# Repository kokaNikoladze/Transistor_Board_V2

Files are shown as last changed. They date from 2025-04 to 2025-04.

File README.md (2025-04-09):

MIDI-CONTROLLED TRANSISTOR DRIVER
---------------------------------

This Arduino sketch turns MIDI messages into PWM voltage outputs to control transistors,
analog circuits, or other devices via 8 digital pins (pins 4–11).

FEATURES:
- Responds to USB MIDI Note On/Off: 
  - Note velocity controls output voltage (0–16383).
- Control Change (CC) support:
  - Channel 2: 7-bit control (0–127), scaled to 14-bit PWM.
  - Channel 1: High-resolution 14-bit NRPN-style control with exponential response.
    (MSB on CC < 64, LSB on CC >= 64)

PIN ASSIGNMENTS:
- Outputs 1–8 → Digital pins 4–11

NRPN FORMAT (FOR CHANNEL 1 HIGH-RES CONTROL):
- Input value: 0–16383
- MSB = value / 128     → Send to control #1 (or any CC < 64)
- LSB = value % 128     → Send to control #65 (or any CC >= 64)
- IMPORTANT: Send LSB first, then MSB

OTHER NOTES:
- Uses 14-bit PWM resolution
- PWM frequency set on pin 1 to 18.384kHz
- Includes exponential curve: pow(result / 16383.0, 3)
- Built for Teensy or other boards with analogWriteResolution()

DEPENDENCIES:
- usbMIDI library (Teensy compatible)

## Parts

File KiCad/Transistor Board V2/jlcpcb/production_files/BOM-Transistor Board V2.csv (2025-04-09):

Comment | Designator | Footprint | LCSC | Quantity
R_Small | R10,R11,R12,R5,R6,R7,R8,R9 | R_0805_2012Metric | C17414 | 8
AO3400A | Q10,Q11,Q12,Q5,Q6,Q7,Q8,Q9 | SOT-23 | C20917 | 8
SS54 | D10,D11,D12,D13,D6,D7,D8,D9 | D_SMA | C22452 | 8
Barrel_Jack_Switch | J1,J15,J3,J4,J5,J6,J7,J8,J9 | DC-005-5A-2.0-SMT | C319134 | 9
DIODE | D2 | TO-220-2_Horizontal_TabDown |  | 1
Conn_01x02_Female | J14 | PinHeader_1x02_P2.54mm_Vertical |  | 1
Teensy4.1 | U1 | Teensy41 |  | 1

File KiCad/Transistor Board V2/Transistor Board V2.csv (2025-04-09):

Comment | Designator | Footprint | LCSC
SS54 | D1,D3,D4,D5,D6,D7,D8,D9,D10,D11,D12,D13 | Diode_SMD:D_SMA | C22452
DIODE | D2 | Package_TO_SOT_THT:TO-220-2_Vertical
Conn_01x02_Female | J1,J3,J4,J5,J6,J7,J8,J9,J10,J11,J12,J13 | Connector_Wire:solenoid_connector
Conn_01x02_Female | J14 | Connector_PinHeader_2.54mm:PinHeader_1x02_P2.54mm_Vertical
PJ-051A | J2 | PJ-051A:CUI_PJ-051A
AO3400A | Q1,Q2,Q3,Q4,Q5,Q6,Q7,Q8,Q9,Q10,Q11,Q12 | Package_TO_SOT_SMD:SOT-23 | C20917
R_Small | R1,R2,R3,R4,R5,R6,R7,R8,R9,R10,R11,R12 | Resistor_SMD:R_0805_2012Metric | C17414
Teensy4.1 | U1 | Teensy:Teensy41

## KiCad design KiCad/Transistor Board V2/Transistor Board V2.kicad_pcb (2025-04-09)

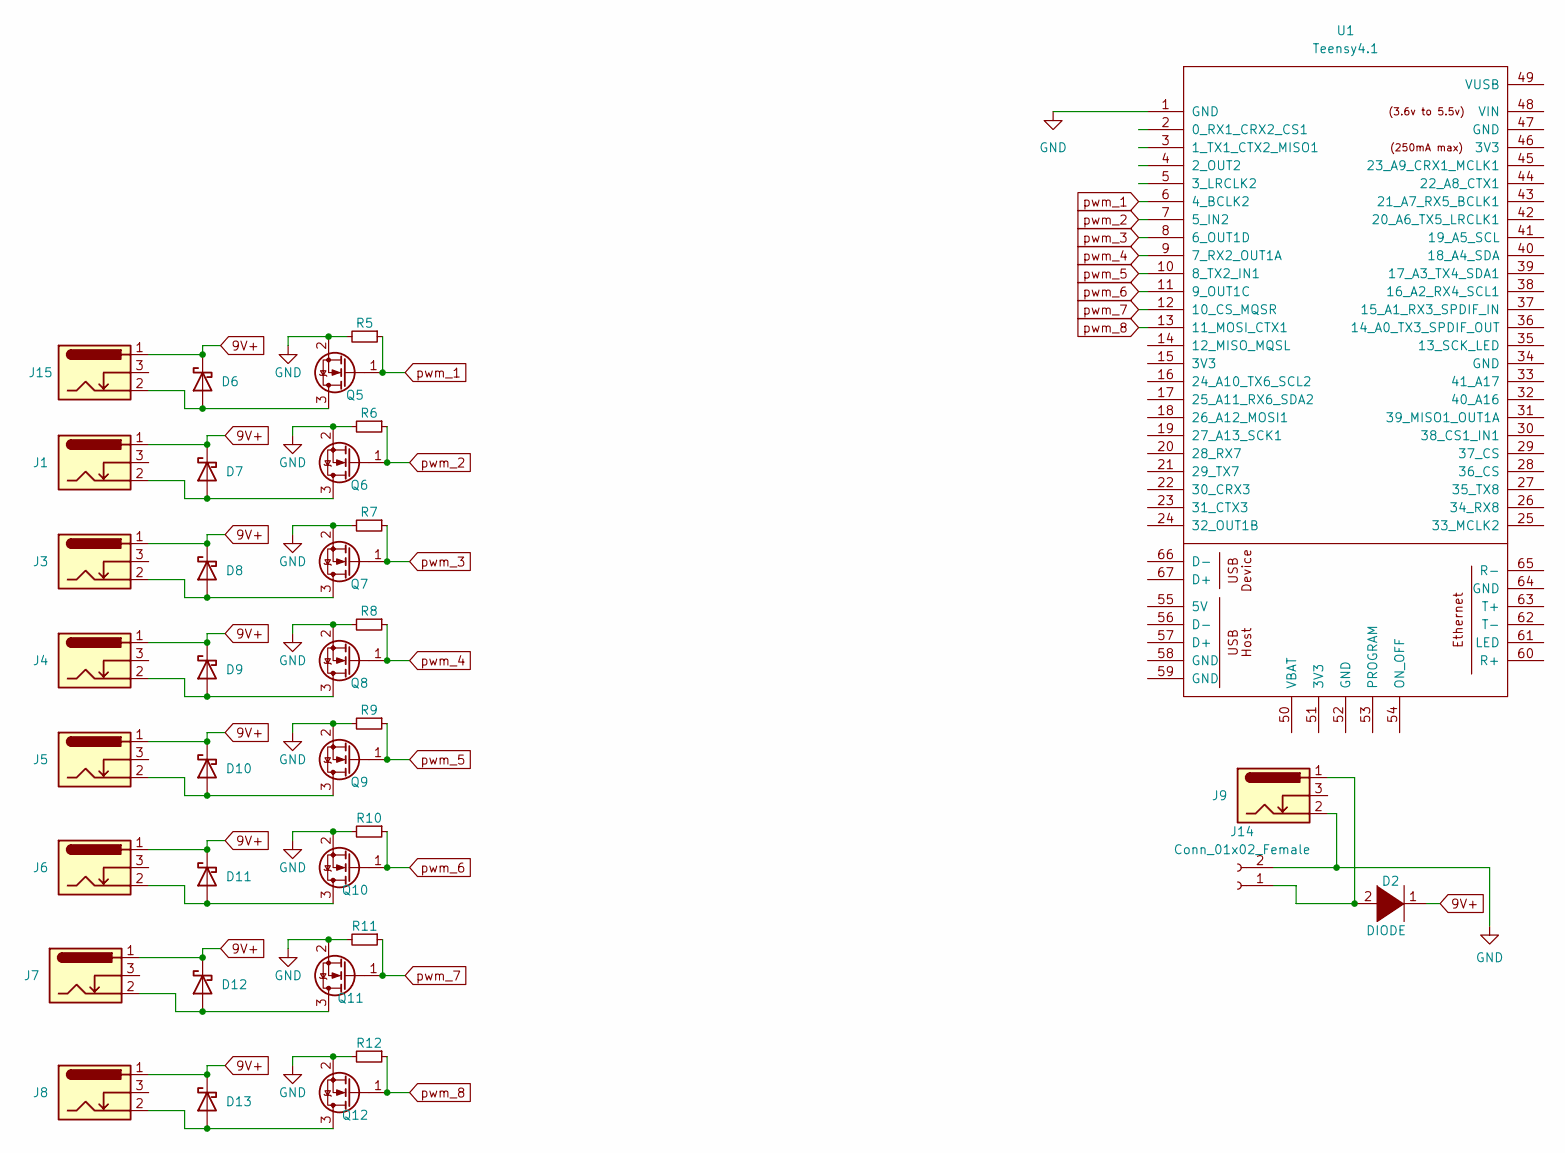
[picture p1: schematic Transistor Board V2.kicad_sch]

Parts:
D2: DIODE; TO-220-2_Horizontal_TabDown
D6, D7, D8, D9, D10, D11, D12, D13: SS54; D_SMA; LCSC C22452
J1, J3, J4, J5, J6, J7, J8, J9, J15: Barrel_Jack_Switch; DC-005-5A-2.0-SMT; LCSC C319134
J14: Conn_01x02_Female; PinHeader_1x02_P2.54mm_Vertical
Q5, Q6, Q7, Q8, Q9, Q10, Q11, Q12: AO3400A; SOT-23; LCSC C20917
R5, R6, R7, R8, R9, R10, R11, R12: R_Small; R_0805_2012Metric; LCSC C17414
U1: Teensy4.1; Teensy41

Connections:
9V+: D2.1 (K), D6.1 (K), D7.1 (K), D8.1 (K), D9.1 (K), D10.1 (K), D11.1 (K), D12.1 (K), D13.1 (K), J1.1, J3.1, J4.1, J5.1, J6.1, J7.1, J8.1, J15.1
GND: J9.2, J14.2, Q5.2 (S), Q6.2 (S), Q7.2 (S), Q8.2 (S), Q9.2 (S), Q10.2 (S), Q11.2 (S), Q12.2 (S), R5.2, R6.2, R7.2, R8.2, R9.2, R10.2, R11.2, R12.2, U1.1 (GND)
unnamed: D2.2 (A), J9.1, J14.1
unnamed: D6.2 (A), J15.2, Q5.3 (D)
unnamed: D7.2 (A), J1.2, Q6.3 (D)
unnamed: D8.2 (A), J3.2, Q7.3 (D)
unnamed: D9.2 (A), J4.2, Q8.3 (D)
unnamed: D10.2 (A), J5.2, Q9.3 (D)
unnamed: D11.2 (A), J6.2, Q10.3 (D)
unnamed: D12.2 (A), J7.2, Q11.3 (D)
unnamed: D13.2 (A), J8.2, Q12.3 (D)
pwm_1: Q5.1 (G), R5.1, U1.6 (4_BCLK2)
pwm_2: Q6.1 (G), R6.1, U1.7 (5_IN2)
pwm_3: Q7.1 (G), R7.1, U1.8 (6_OUT1D)
pwm_4: Q8.1 (G), R8.1, U1.9 (7_RX2_OUT1A)
pwm_5: Q9.1 (G), R9.1, U1.10 (8_TX2_IN1)
pwm_6: Q10.1 (G), R10.1, U1.11 (9_OUT1C)
pwm_7: Q11.1 (G), R11.1, U1.12 (10_CS_MQSR)
pwm_8: Q12.1 (G), R12.1, U1.13 (11_MOSI_CTX1)
pwm_9: U1.14 (12_MISO_MQSL)

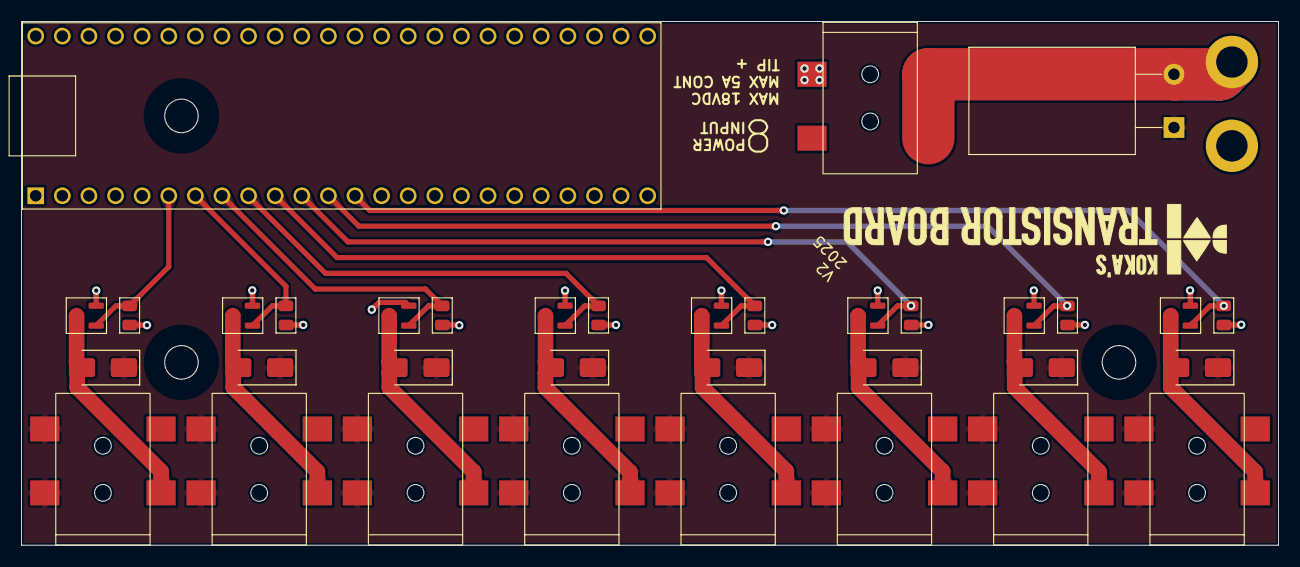
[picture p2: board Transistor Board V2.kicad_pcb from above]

Board: 2 copper layers, 120.0 x 50.0 mm, 36 parts (0 on the bottom side), 19 nets.

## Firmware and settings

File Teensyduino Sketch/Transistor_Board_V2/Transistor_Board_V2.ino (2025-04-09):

byte my_buffer[128] = {};
int result;
float exponentionalize;


byte b2;
byte pinMap[] = {4, 5, 6, 7, 8, 9, 10, 11};

void setup() {

  analogWriteResolution(14);
  analogWriteFrequency(1, 18384);

  pinMode(13, OUTPUT);
  digitalWrite(13, HIGH);

  usbMIDI.setHandleNoteOn(OnNoteOn);
  usbMIDI.setHandleNoteOff(OnNoteOff);
  usbMIDI.setHandleControlChange(myControlChange);

  for (int i=0; i<8; i++) {
    pinMode(pinMap[i], OUTPUT);
  }
}

void loop() {

  usbMIDI.read();

}

void OnNoteOn(byte channel, byte note, byte vel) {
  analogWrite(pinMap[note - 1], vel * 128);
  Serial.println(note);
}

void OnNoteOff(byte channel, byte note, byte vel) {
  analogWrite(pinMap[note - 1], 0);
}

void myControlChange(byte channel, byte control, byte value) {

  if (channel == 1) {

    if (control >= 64) {
      b2 = value;
      //Serial.println(">64");
    } else {
      result = (value << 7) | b2;
      exponentionalize = pow((float)result / 16383, 3);
      analogWrite(pinMap[control - 1], exponentionalize * 16383);
      //Serial.print("result ---"); Serial.print(result ); Serial.println();
    }
  } else if (channel == 2) {
    analogWrite(pinMap[control - 1], value * 127);
  }
}
